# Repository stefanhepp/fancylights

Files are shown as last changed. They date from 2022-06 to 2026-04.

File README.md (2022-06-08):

FancyLights
===========

This is the sourcecode and plans for my home LED light and projector control system.

Content
=======

This project consists of the following controller boards:
- `keypad`: Sources for a keypad controller that communicates via RS232 with the main controller board and via I2C with a Raspberry PI.
- `fancycontrol`: Sources for the main light controller, which controls the lights and screen, and communicates via I2C with the projector control board.
- `projector`: Sources for the projector control board, which controls a servo for the projector mount locking mechanism and communicates via RS232 with the projector.

This repository contains the following folders:
- `kicad`: KiCAD schematics for all boards.
- `src`: Sources for all AtMega microcontrollers.

License
=======

This program is free software: you can redistribute it and/or modify
it under the terms of the GNU General Public License as published by
the Free Software Foundation, either version 3 of the License, or
(at your option) any later version.

This program is distributed in the hope that it will be useful,
but WITHOUT ANY WARRANTY; without even the implied warranty of
MERCHANTABILITY or FITNESS FOR A PARTICULAR PURPOSE.  See the
GNU General Public License for more details.

You should have received a copy of the GNU General Public License
along with this program.  If not, see <https://www.gnu.org/licenses/>.

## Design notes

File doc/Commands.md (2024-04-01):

Commands
========

Keypad
------

I2C: Slave Addr

o) I2C Receive
- 3D On
- 3D Format
- Set RBG Color: 
- Light On
- Light Off
- Set Brightness
- Projector Up
- Projector Down

UART: 

o) UART Send
- 

Controller
----------

UART Projector:

o) UART Projector Send:
- 

o) UART Projector Receive:
- 

Acer 650
--------

UART: 9600baud

o) UART Send
- Power On:  2a 20 30 20 49 52 20 30 30 31 0d
- Power Off: 2a 20 30 20 49 52 20 30 30 32 0d
- Mute:      2a 20 30 20 49 52 20 30 30 36 0d
- Volume Up: 2a 20 30 20 49 52 20 30 32 33 0d
- Volume Dn: 2a 20 30 20 49 52 20 30 32 34 0d
- Eco Mode:  2a 20 30 20 49 52 20 30 35 31 0d
- 3D On:     2a 20 30 20 49 52 20 30 35 36 0d
- 3D Off:    2a 20 30 20 49 52 20 30 35 37 0d
- 2D to 3D On:  2a 20 30 20 49 52 20 30 35 38 0d
- 2D to 3D Off: 2a 20 30 20 49 52 20 30 35 39 0d
- 3D SbS Half:  2a 20 30 20 49 52 20 30 36 32 0d
- 3D SbS Full:  2a 20 30 20 49 52 20 30 36 33 0d
- 3D Top/Btm:   2a 20 30 20 49 52 20 30 36 34 0d
- 3D L/R invert: 2a 20 30 20 49 52 20 30 36 35 0d 

- Query Lamp hours:  2a 20 30 20 4c 61 6d 70 0d
- Query Lamp On/Off: 2a 20 30 20 4c 61 6d 70 20 3f 0d

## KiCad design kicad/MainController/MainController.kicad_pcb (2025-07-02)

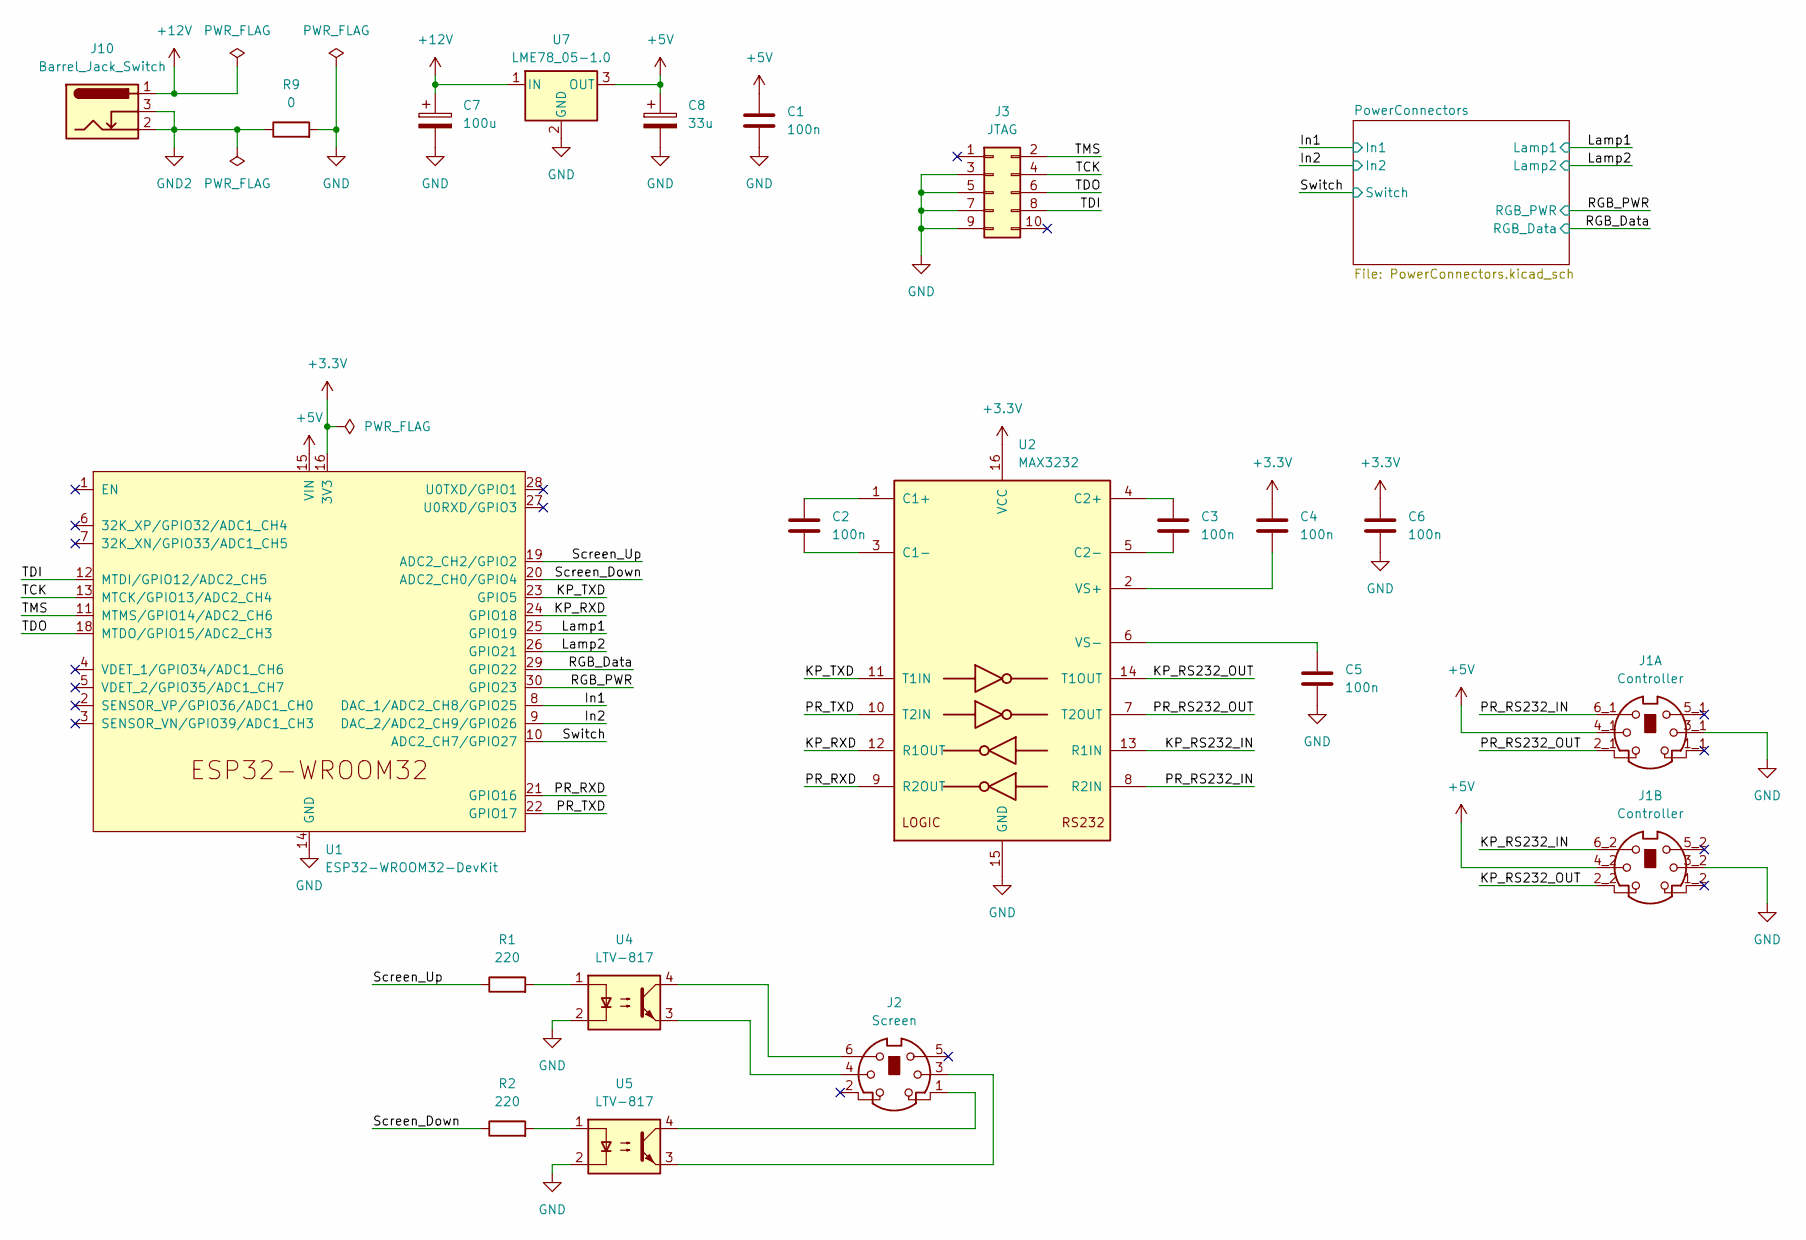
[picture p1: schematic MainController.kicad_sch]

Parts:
C1, C2, C3, C4, C5, C6: 100n; C_Disc_D3.4mm_W2.1mm_P2.50mm
C7: 100u; CP_Radial_D7.5mm_P2.50mm
C8: 33u; CP_Radial_D5.0mm_P2.50mm
J1: Controller; SWITCHCRAFT_DMD6FRA111
J2: Screen; MiniDIN TE_5749180-1
J3: JTAG; IDC-Header_2x05_P2.54mm_Vertical
J10: Barrel_Jack_Switch; BarrelJack_Horizontal
R1, R2: 220; R_Axial_DIN0207_L6.3mm_D2.5mm_P10.16mm_Horizontal
R9: 0; R_Axial_DIN0207_L6.3mm_D2.5mm_P10.16mm_Horizontal
U1: ESP32-WROOM32-DevKit; ESP32-WROOM32-DevKit_NoMountingHoles
U2: MAX3232; SOIC-16_3.9x9.9mm_P1.27mm
U4, U5: LTV-817; DIP-4_W7.62mm
U7: LME78_05-1.0; Converter_DCDC_GAPTEC_LME78_05-1.0

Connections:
+3.3V: C4.2, C6.1, U1.16 (3V3), U2.16 (VCC)
+5V: C1.1, C8.1, J1.4_1, J1.4_2, U1.15 (VIN), U7.3 (OUT); also elsewhere on the board
+12V: C7.1, J10.1, U7.1 (IN); also elsewhere on the board
/In1: U1.8 (DAC_1/ADC2_CH8/GPIO25); also elsewhere on the board
/In2: U1.9 (DAC_2/ADC2_CH9/GPIO26); also elsewhere on the board
/KP_RS232_IN: J1.6_2, U2.13 (R1IN)
/KP_RS232_OUT: J1.2_2, U2.14 (T1OUT)
/KP_RXD: U1.24 (GPIO18), U2.12 (R1OUT)
/KP_TXD: U1.23 (GPIO5), U2.11 (T1IN)
/Lamp1: U1.25 (GPIO19); also elsewhere on the board
/Lamp2: U1.26 (GPIO21); also elsewhere on the board
/PR_RS232_IN: J1.6_1, U2.8 (R2IN)
/PR_RS232_OUT: J1.2_1, U2.7 (T2OUT)
/PR_RXD: U1.21 (GPIO16), U2.9 (R2OUT)
/PR_TXD: U1.22 (GPIO17), U2.10 (T2IN)
/RGB_Data: U1.29 (GPIO22); also elsewhere on the board
/RGB_PWR: U1.30 (GPIO23); also elsewhere on the board
/Screen_Down: R2.1, U1.20 (ADC2_CH0/GPIO4)
/Screen_Up: R1.1, U1.19 (ADC2_CH2/GPIO2)
/Switch: U1.10 (ADC2_CH7/GPIO27); also elsewhere on the board
/TCK: J3.4, U1.13 (MTCK/GPIO13/ADC2_CH4)
/TDI: J3.8, U1.12 (MTDI/GPIO12/ADC2_CH5)
/TDO: J3.6, U1.18 (MTDO/GPIO15/ADC2_CH3)
/TMS: J3.2, U1.11 (MTMS/GPIO14/ADC2_CH6)
GND: C1.2, C5.2, C6.2, C7.2, C8.2, J1.3_1, J1.3_2, J3.3, J3.5, J3.7, J3.9, R9.2, U1.14 (GND), U1.17 (GND), U2.15 (GND), U4.2, U5.2, U7.2 (GND); also elsewhere on the board
GND2: J10.2, J10.3, R9.1; also elsewhere on the board
unnamed: J2.1, U5.4
unnamed: J2.3, U5.3
unnamed: J2.4, U4.3
unnamed: J2.6, U4.4
unnamed: R1.2, U4.1
unnamed: R2.2, U5.1
unnamed: C2.1, U2.1 (C1+)
unnamed: C2.2, U2.3 (C1-)
unnamed: C3.1, U2.4 (C2+)
unnamed: C3.2, U2.5 (C2-)
unnamed: C4.1, U2.2 (VS+)
unnamed: C5.1, U2.6 (VS-)

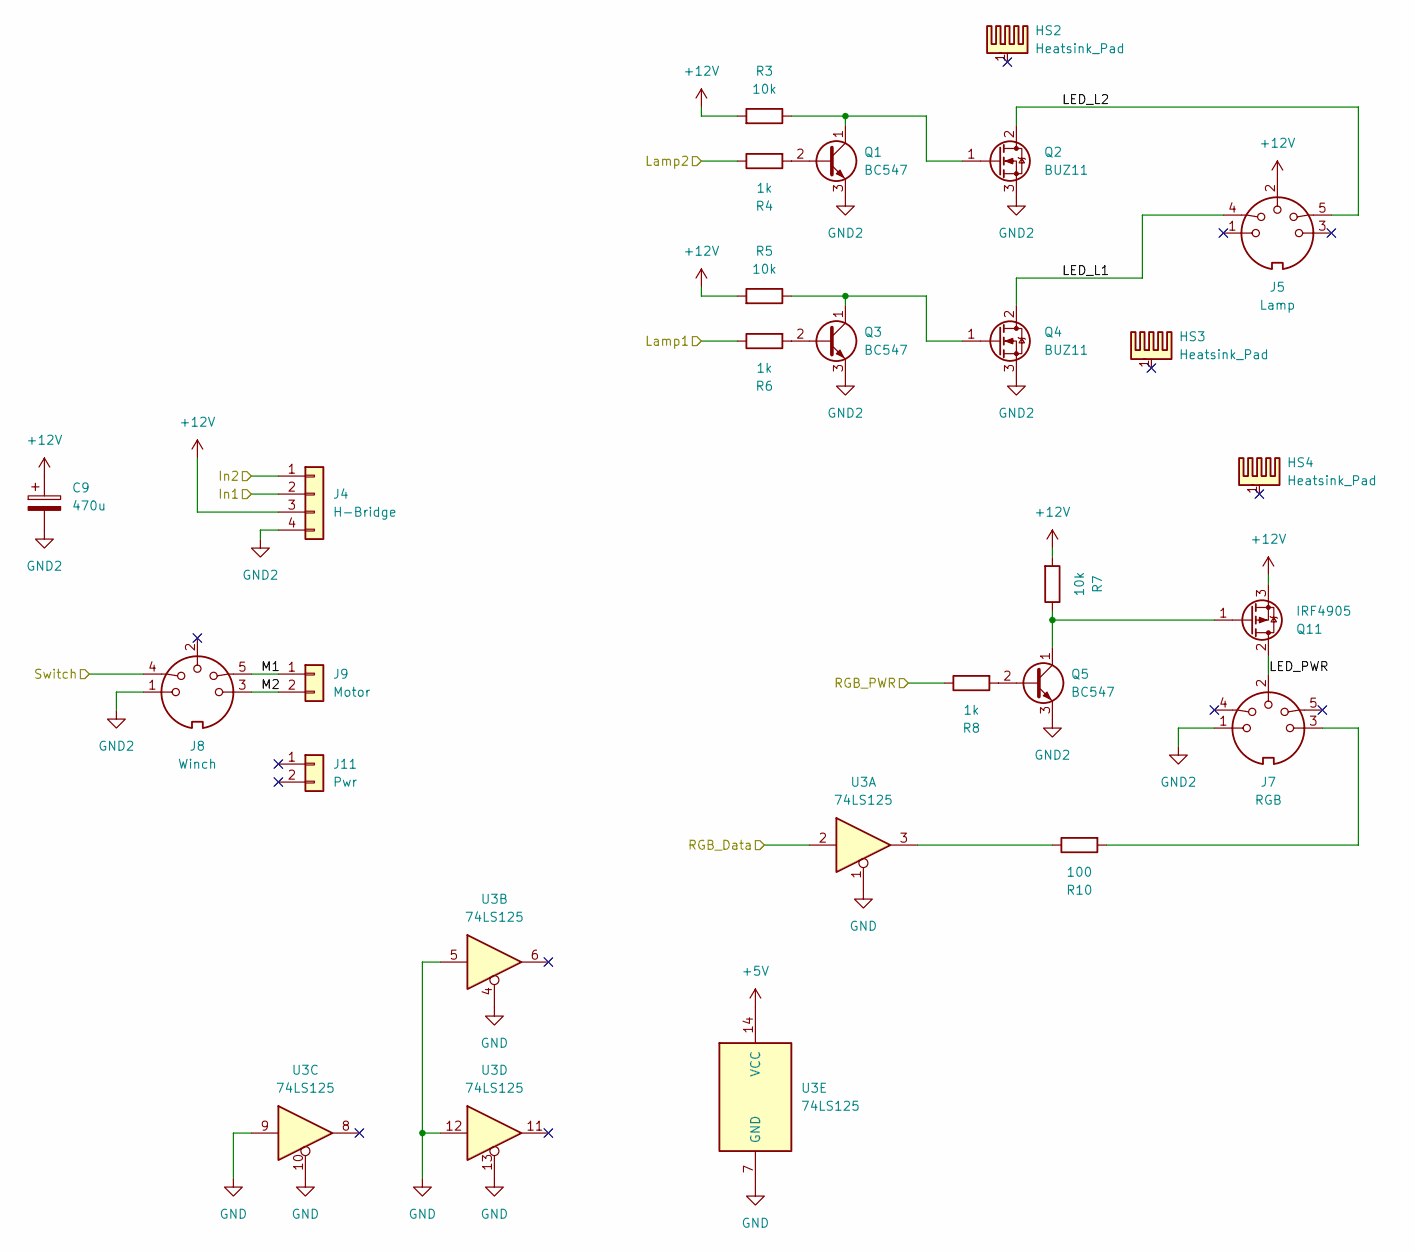
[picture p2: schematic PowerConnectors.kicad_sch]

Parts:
C9: 470u; CP_Radial_D10.0mm_P5.00mm
HS2, HS3, HS4: Heatsink_Pad; Heatsink_Aavid_TO-220_H12.7mm
J4: H-Bridge; PinHeader_1x04_P2.54mm_Vertical
J5: Lamp; DIN-5 MAB5P
J7: RGB; DIN-5 MAB5P
J8: Winch; DIN-5 MAB5P
J9: Motor; PinHeader_1x02_P2.54mm_Vertical
J11: Pwr; PinHeader_1x02_P2.54mm_Vertical
Q1, Q3, Q5: BC547; TO-92_Milling
Q2, Q4: BUZ11; TO-220-3_Vertical
Q11: IRF4905; TO-220-3_Vertical
R3, R5: 10k; R_Axial_DIN0207_L6.3mm_D2.5mm_P2.54mm_Vertical
R4, R6, R8: 1k; R_Axial_DIN0207_L6.3mm_D2.5mm_P10.16mm_Horizontal
R7: 10k; R_Axial_DIN0207_L6.3mm_D2.5mm_P10.16mm_Horizontal
R10: 100; R_Axial_DIN0207_L6.3mm_D2.5mm_P10.16mm_Horizontal
U3: 74LS125; DIP-14_W7.62mm

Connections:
+5V: U3.14 (VCC); also elsewhere on the board
+12V: C9.1, J4.3, J5.2, Q11.3 (S), R3.2, R5.2, R7.2; also elsewhere on the board
/In1: J4.2; also elsewhere on the board
/In2: J4.1; also elsewhere on the board
/Lamp1: R6.1; also elsewhere on the board
/Lamp2: R4.1; also elsewhere on the board
/PowerConnectors/LED_L1: J5.4, Q4.2 (D)
/PowerConnectors/LED_L2: J5.5, Q2.2 (D)
/PowerConnectors/LED_PWR: J7.2, Q11.2 (D)
/PowerConnectors/M1: J8.5, J9.1
/PowerConnectors/M2: J8.3, J9.2
/RGB_Data: U3.2; also elsewhere on the board
/RGB_PWR: R8.1; also elsewhere on the board
/Switch: J8.4; also elsewhere on the board
GND: U3.1, U3.4, U3.5, U3.7 (GND), U3.9, U3.10, U3.12, U3.13; also elsewhere on the board
GND2: C9.2, J4.4, J7.1, J8.1, Q1.3 (E), Q2.3 (S), Q3.3 (E), Q4.3 (S), Q5.3 (E); also elsewhere on the board
unnamed: J7.3, R10.2
unnamed: Q1.2 (B), R4.2
unnamed: Q1.1 (C), Q2.1 (G), R3.1
unnamed: Q3.2 (B), R6.2
unnamed: Q3.1 (C), Q4.1 (G), R5.1
unnamed: Q5.2 (B), R8.2
unnamed: Q5.1 (C), Q11.1 (G), R7.1
unnamed: R10.1, U3.3

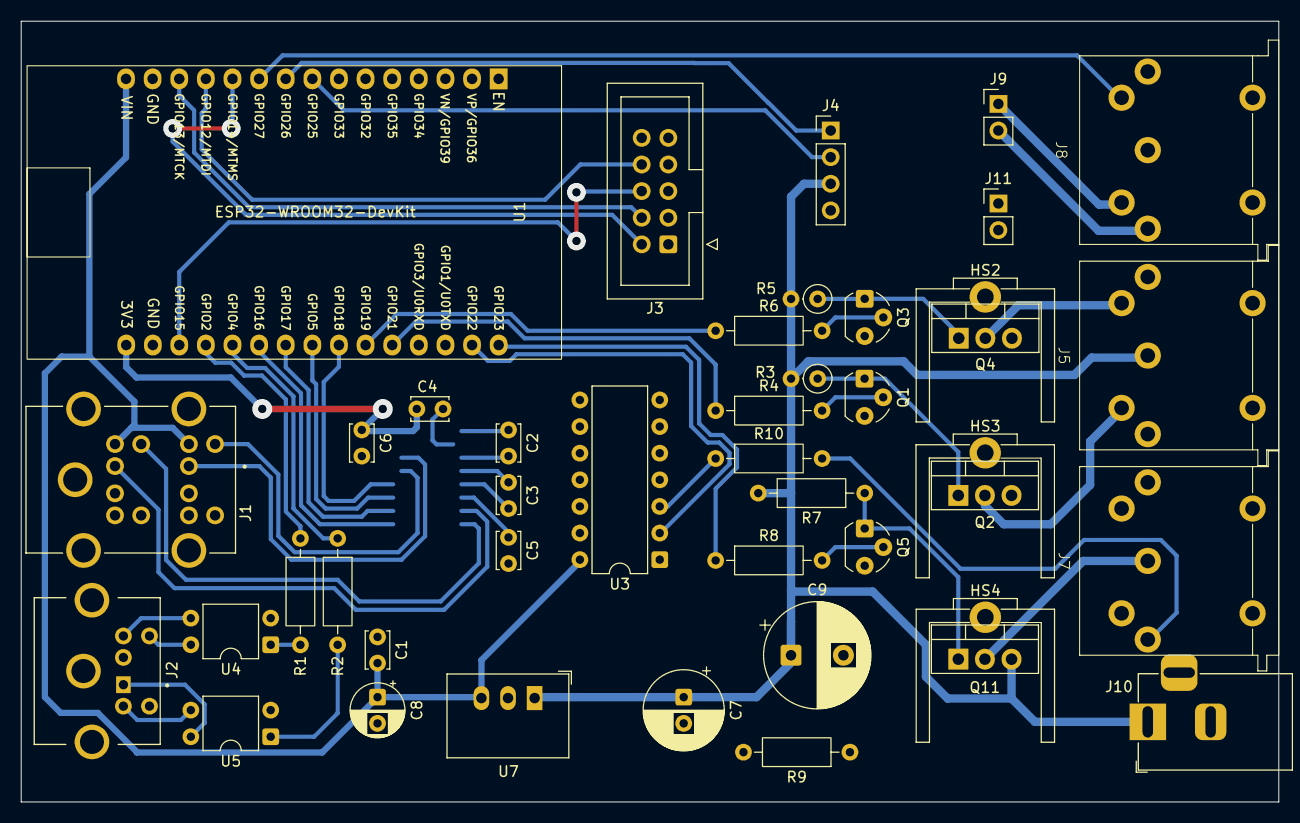
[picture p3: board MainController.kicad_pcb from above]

Board: 2 copper layers, 120.0 x 74.5 mm, 44 parts (1 on the bottom side), 51 nets.

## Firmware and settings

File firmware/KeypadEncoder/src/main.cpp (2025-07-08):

/*
 * @project     FancyController
 * @author      Stefan Hepp, stefan@stefant.org
 *
 * Keypad main loop implementation.
 *
 * Copyright 2024 Stefan Hepp
 * License: GPL v3
 * See 'COPYRIGHT.txt' for copyright and licensing information.
 */
#include <Arduino.h>
#include <MegaWire.h>

#include <commands.h>

#include "config.h"
#include "Keypad.h"
#include "LightState.h"

// Create device driver instances
MegaWire Wire;

Keypad keypad;
LightState LState;

bool LightSwitch = true;

bool StatusReceived = false;

// Toggle projector power after receiving the status from the controller back
bool ToggleProjectorPowerOnStatus = false;

static const uint8_t IRQ_COMMAND = 0;
static const uint8_t IRQ_STATUS = 1;

static uint16_t IRQFlags = 0x00;

static uint8_t I2CCommand = 0x00;

static const int I2C_BUFFER_SIZE = 16;
static uint8_t I2CBuffer[I2C_BUFFER_SIZE];
static uint8_t I2CBufferLength = 0;

static const int UART_BUFFER_SIZE = 16;
static uint8_t UARTBuffer[UART_BUFFER_SIZE];
static uint8_t UARTBufferLength = 0;

static void sendIRQ(uint8_t flag)
{
    IRQFlags |= (1<<flag);
    digitalWrite(PIN_INTERRUPT, HIGH);
}

static void clearIRQ(uint8_t flag)
{
    IRQFlags &= ~(1<<flag);
    if (IRQFlags == 0x00) {
        digitalWrite(PIN_INTERRUPT, LOW);
    }
}

void sendCommand(uint8_t command, uint8_t value, bool sendI2C = true) 
{
    switch (command) {
        case CommandOpcode::CMD_LIGHT_MODE:
            LState.setLightMode(value);
            break;
        case CommandOpcode::CMD_LIGHT_INTENSITY:
            LState.setIntensity(value);
            break;       
        case CommandOpcode::CMD_RGB_MODE:
            LState.setRGBMode(value);
            break;
        case CommandOpcode::CMD_PROJECTOR_MODE:
            LState.setProjectorMode(value);
            break;
    }

    Serial.write(CMD_HEADER | command);
    Serial.write(value);

    if (sendI2C) {
        noInterrupts();
        if (I2CBufferLength < I2C_BUFFER_SIZE - 1) {
            I2CBuffer[I2CBufferLength++] = CMD_HEADER | command;
            I2CBuffer[I2CBufferLength++] = value;
        }
        interrupts();
        sendIRQ(IRQ_COMMAND);
    }
}

void requestStatus() {
    clearIRQ(IRQ_STATUS);
    sendCommand(CommandOpcode::CMD_REQUEST_STATUS, 0, false);
}

void sendHSVColor(bool sendI2C = true)
{
    Serial.write(CMD_HEADER | CMD_HSV_COLOR);
    Serial.write(LState.hsv(0));
    Serial.write(LState.hsv(1));
    Serial.write(LState.hsv(2));

    requestStatus();
}

void processKeypadCommand(uint8_t data)
{
    if (UARTBufferLength == 0 && (data & CMD_HEADER) != CMD_HEADER) {
        // Wait for command byte, drop other data
        return;
    }

    if (UARTBufferLength < UART_BUFFER_SIZE) {
        UARTBuffer[UARTBufferLength++] = data;
    }

    switch (UARTBuffer[0] & ~CMD_HEADER) {
        case CMD_READ_STATUS:
            if (UARTBufferLength >= 9) {
                // command completely received
                LState.setLightMode(UARTBuffer[1]);
                LState.setIntensity(UARTBuffer[2]);
                LState.setDimmedIntensity(UARTBuffer[3]);
                LState.setProjectorMode(UARTBuffer[4]);
                LState.setRGBMode(UARTBuffer[5]);
                LState.setHSV(UARTBuffer[6], UARTBuffer[7], UARTBuffer[8]);

                UARTBufferLength = 0;
                StatusReceived = true;

                // We got a new status, inform RPi to fetch the new status
                sendIRQ(IRQ_STATUS);

                if (ToggleProjectorPowerOnStatus) {
                    // If this status was requested by a Projector power toggle button, perform the action now.
                    LState.toggleProjector();
                    sendCommand(CMD_PROJECTOR_MODE, LState.projectorMode());
                    
                    ToggleProjectorPowerOnStatus = false;
                }
            }
            break;
        default:
            // unknown command, drop
            UARTBufferLength = 0;
            break;
    }
}

void onButtonPress(uint8_t btn, bool longPress)
{
    switch (btn) {
        case 0: // 3D mode
            sendCommand(CMD_PROJECTOR_MODE, PROJECTOR_3D);
            sendCommand(CMD_RGB_MODE, RGB_DIMMED);
            break;
        case 1: // VR mode
            sendCommand(CMD_PROJECTOR_MODE, PROJECTOR_VR);
            sendCommand(CMD_RGB_MODE, RGB_ON);
            break;
        case 2: // Color cycle forward
            if (longPress) {
                sendCommand(CMD_RGB_MODE, RGB_CYCLE);
            } else if (LState.rgbMode() != RGB_ON) {
                sendCommand(CMD_RGB_MODE, RGB_ON);
            } else {
                LState.changeHSVHue(16);
                sendHSVColor();
            }
            break;
        case 3: // Color cycle back
            if (longPress) {
                sendCommand(CMD_RGB_MODE, RGB_CYCLE);
            } else if (LState.rgbMode() != RGB_ON) {
                sendCommand(CMD_RGB_MODE, RGB_ON);
            } else {
                LState.changeHSVHue(-16);
                sendHSVColor();
            }
            break;
        case 4: // Fire mode
            sendCommand(CMD_RGB_MODE, RGB_FIRE);
            break;
        case 5: // Movie mode
            sendCommand(CMD_PROJECTOR_MODE, PROJECTOR_NORMAL);
            sendCommand(CMD_RGB_MODE, longPress ? RGB_ON : RGB_DIMMED);
            break;
        case 6: // RGB saturation down
            LState.changeHSVSaturation(longPress ? -255 : -32);
            sendHSVColor();
            break;
        case 7: // RGB saturation up
            LState.changeHSVSaturation(longPress ? 255 : 32);
            sendHSVColor();
            break;
        case 8: // Screen down
            if (longPress) {
                sendCommand(CMD_SCREEN, LIFT_STOP);
            } else {
                sendCommand(CMD_SCREEN, LIFT_DOWN);
            }        
            break;
        case 9: // Screen up
            if (longPress) {
                sendCommand(CMD_SCREEN, LIFT_STOP);
            } else {
                sendCommand(CMD_SCREEN, LIFT_UP);
            }        
            break;
        case 10: // Intensity down
            LState.changeIntensity(longPress ? -255 : -32);
            sendCommand(CMD_LIGHT_INTENSITY, LState.lightIntensity());
            sendHSVColor();
            break;
        case 11: // Intensity up
            LState.changeIntensity(longPress ? 255 : 32);
            sendCommand(CMD_LIGHT_INTENSITY, LState.lightIntensity());
            sendHSVColor();
            break;
        case 12: // Projector down
            if (longPress) {
                sendCommand(CMD_PROJECTOR_LIFT, LIFT_STOP);    
            } else {
                sendCommand(CMD_PROJECTOR_LIFT, LIFT_DOWN);
            }        
            break;
        case 13: // Projector up
            if (longPress) {
                sendCommand(CMD_PROJECTOR_LIFT, LIFT_STOP);    
            } else {
                sendCommand(CMD_PROJECTOR_LIFT, LIFT_UP);
            }
            break;
        case 14: // Projector on/off
            // Read the status of the projector first, Delay toggling till we receive the message
            ToggleProjectorPowerOnStatus = true;
            sendCommand(CMD_REQUEST_STATUS, 0);
            break;
        case 15: // Light on/off
            LState.toggleLight();
            sendCommand(CMD_LIGHT_MODE, LState.lightMode());
            break;
    }
}

void i2cReceive(uint8_t length) {
    uint8_t I2CCommand = Wire.read();
    uint8_t value;

    switch (I2CCommand) {
        case CommandOpcode::CMD_LIGHT_MODE:
        case CommandOpcode::CMD_LIGHT_INTENSITY:
        case CommandOpcode::CMD_DIMMED_INTENSITY:
        case CommandOpcode::CMD_RGB_MODE:
        case CommandOpcode::CMD_SCREEN:
        case CommandOpcode::CMD_PROJECTOR_MODE:
        case CommandOpcode::CMD_PROJECTOR_LIFT:
            value = Wire.read();

            // Forward command to controller
            sendCommand(I2CCommand, value, false);
            break;
        case CommandOpcode::CMD_HSV_COLOR:
            if (Wire.available() > 2) {
                LState.setHSV(Wire.read(), 
                              Wire.read(), 
                              Wire.read());
                sendHSVColor(false);
            }
            break;
        case CommandOpcode::CMD_REQUEST_STATUS:
            requestStatus();
            break;
        case CommandOpcode::CMD_READ_COMMANDS:
        case CommandOpcode::CMD_READ_STATUS:
            // expect i2c read request after this write
            break;
    }
}

void i2cRequest()
{
    switch (I2CCommand) {
        case CommandOpcode::CMD_READ_COMMANDS:
            Wire.write(I2CBufferLength | (IRQFlags & (1<<IRQ_STATUS) ? 0x80 : 0) );

            for (uint8_t i = 0; i < I2CBufferLength; i++) {
                Wire.write(I2CBuffer[i]);
            }

            I2CBufferLength = 0;

            clearIRQ(IRQ_COMMAND);
            break;
        case CommandOpcode::CMD_READ_STATUS:
            Wire.write(LState.lightMode());
            Wire.write(LState.lightIntensity());
            Wire.write(LState.dimmedIntensity());
            Wire.write(LState.projectorMode());
            Wire.write(LState.rgbMode());
            Wire.write(LState.hsv(0));
            Wire.write(LState.hsv(1));
            Wire.write(LState.hsv(2));

            clearIRQ(IRQ_STATUS);
            break;
    }
}

void setup() {
    // Enable pullups for unconnected pins
    pinMode(PIN_PB1, INPUT_PULLUP);
    pinMode(PIN_PB2, INPUT_PULLUP);
    pinMode(PIN_PB3, INPUT_PULLUP);
    pinMode(PIN_PB4, INPUT_PULLUP);
    pinMode(PIN_PB5, INPUT_PULLUP);
    pinMode(PIN_PB6, INPUT_PULLUP);
    pinMode(PIN_PB7, INPUT_PULLUP);
    pinMode(PIN_PC6, INPUT_PULLUP);
    pinMode(PIN_PD3, INPUT_PULLUP);

    pinMode(PIN_SWITCH, INPUT_PULLUP);

    // Set output pin modes
    // Set pin value first before turing on output mode, to prevent spurious signals
    digitalWrite(PIN_INTERRUPT, LOW);
    pinMode(PIN_INTERRUPT, OUTPUT);

    Wire.onReceive(i2cReceive);
    Wire.onRequest(i2cRequest);
    keypad.setPressEvent(onButtonPress);

    Serial.begin(UART_SPEED_CONTROLLER);

    Wire.begin(KEYPAD_I2C_ADDR);
    keypad.begin();

    StatusReceived = true;
    delay(500);
    sendCommand(CMD_REQUEST_STATUS, 0);
}

void loop() {
    if (StatusReceived) {
        keypad.poll();

        uint8_t newSwitchState = digitalRead(PIN_SWITCH);
        if (newSwitchState != LightSwitch) {
            LState.toggleLight();

            sendCommand(CMD_LIGHT_MODE, LState.lightMode());

            LightSwitch = newSwitchState;
        }
    }

    while (Serial.available()) {
        int data = Serial.read();

        processKeypadCommand(data);
    }
}

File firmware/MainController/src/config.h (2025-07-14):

/*
 * @project     FancyLights
 * @author      Stefan Hepp, stefan@stefant.org
 *
 * common custom IO and config settings.
 *
 * Copyright (c) 2024 Stefan Hepp
 * License: GPL v3
 * See 'COPYRIGHT.txt' for copyright and licensing information.
 */
#pragma once

#include <Arduino.h>

/* ==================================================== */
/* Common controller settings                           */
/* ==================================================== */

static const uint8_t PIN_RGB_DATA     = 22;
static const uint8_t PIN_RGB_PWR      = 23;
static const uint8_t PIN_LAMP1        = 19;
static const uint8_t PIN_LAMP2        = 21;
static const uint8_t PIN_SCREEN_UP    = 4;
static const uint8_t PIN_SCREEN_DOWN  = 2;
static const uint8_t PIN_WINCH_SWITCH = 27;
static const uint8_t PIN_MOTOR_IN1    = 25;
static const uint8_t PIN_MOTOR_IN2    = 26;

static const uint8_t UART_KEYPAD      = 1;
static const uint8_t UART_PROJECTOR   = 2;

static const uint8_t PIN_KP_TXD       = 5;
static const uint8_t PIN_KP_RXD       = 18;
static const uint8_t PIN_PR_TXD       = 17;
static const uint8_t PIN_PR_RXD       = 16;

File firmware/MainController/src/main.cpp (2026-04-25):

/*
 * @project     FancyLights
 * @author      Stefan Hepp, stefan@stefant.org
 *
 * Controller main loop implementation.
 *
 * Copyright 2024 Stefan Hepp
 * License: GPL v3
 * See 'COPYRIGHT.txt' for copyright and licensing information.
 */

#include <Arduino.h>

#include <WiFi.h>
#include <PubSubClient.h>
#include <FastLED.h>

#include <commands.h>

#include "config.h"
#include "CommandLine.h"
#include "LED.h"
#include "Settings.h"
#include "ProjectorController.h"
#include "KeypadDriver.h"
#include "MqttClient.h"

Settings settings;
CommandLine cmdline;
MqttClient mqttClient(settings);
LEDDriver LEDs(settings, mqttClient);
ProjectorController Projector(settings, mqttClient);
KeypadDriver Keypad(settings, LEDs, Projector);


class StatusParser: public CommandParser
{
    public:
        StatusParser() {}

        virtual CmdExecStatus completeCommand(bool expectCommand) {
            IPAddress mqttAddr;
            WiFi.hostByName(settings.getMQTTServer().c_str(), mqttAddr);

            Serial.printf("Enable Lamp: %s, LED Strip: %s\n", strBool(LEDs.isLampEnabled()), strBool(LEDs.isLEDStripEnabled()));
            Serial.printf("Light Intensity: %hhu\n", LEDs.intensity());
            Serial.printf("Dimmed Intensity: %hhu\n", LEDs.dimmedIntensity());
            Serial.printf("RGB Strip Mode: %s\n", strRGBMode(LEDs.rgbMode()));
            Serial.printf("Projector Mode: %s\n", strProjectorCommand(Projector.mode()));
            Serial.printf("HSV: %hhu %hhu %hhu\n", LEDs.getHSV().hue, LEDs.getHSV().sat, LEDs.getHSV().val);
            Serial.printf("WiFi SSID: %s PW: %s\n", settings.getWiFiSSID(), settings.getWiFiPassword());
            Serial.printf("WiFi Hostname %s IP %s DNS %s\n", WiFi.getHostname(), WiFi.localIP().toString(), WiFi.dnsIP().toString());
            Serial.printf("WiFi Status (%d) %s\n", WiFi.status(), WiFi.status() == WL_CONNECTED ? "connected" : "not connected");
            Serial.printf("MQTT Server %s:%d IP: %s\n", settings.getMQTTServer(), settings.getMQTTPort(), mqttAddr.toString());
            Serial.printf("MQTT Client %s Topic %s\n", settings.getMQTTClientID(), settings.getMQTTTopic());
            Serial.printf("MQTT User %s Pass: %s\n", settings.getMQTTUsername(), settings.getMQTTPassword());
            Serial.printf("MQTT Status %s\n", mqttClient.connected() ? "connected" : "not connected");

            Projector.requestStatus();

            return CmdExecStatus::CESOK;
        }
};

class WiFiParser: public CommandParser {
    private:
        enum WiFiCommand {
            WIC_NONE,
            WIC_AP,
            WIC_HOSTNAME,
            WIC_CONNECT
        };
        WiFiCommand mCmd;

        String mSSID;
        String mPassword;
        String mHostname;

    public:
        WiFiParser() {}

        virtual void printArguments() {
            Serial.print("ap <ssid> <password>|hostname <hostname>|reconnect");
        }

        virtual CmdParseStatus startCommand(const char* cmd) {
            mCmd = WIC_NONE;
            return CPSNextArgument;
        }

        virtual CmdParseStatus parseNextArgument(int argNo, const char* arg) {
            if (argNo == 0) {
                if (strcmp(arg, "ap") == 0) {
                    mCmd = WIC_AP;
                    return CPSNextArgument;
                }
                if (strcmp(arg, "hostname") == 0) {
                    mCmd = WIC_HOSTNAME;
                    return CPSNextArgument;
                }
                if (strcmp(arg, "reconnect") == 0) {
                    mCmd = WIC_CONNECT;
                    return CPSComplete;
                }
            }
            if (mCmd == WIC_AP && argNo == 1) {
                mSSID = arg;
                return CPSNextArgument;
            }
            if (mCmd == WIC_AP && argNo == 2) {
                mPassword = arg;
                return CPSComplete;
            }
            if (mCmd == WIC_HOSTNAME && argNo == 1) {
                mHostname = arg;
                return CPSComplete;
            }
            return CPSInvalidArgument;
        }

        virtual CmdExecStatus completeCommand(bool expectCommand) {
            if (mCmd == WIC_AP) {
                settings.setWiFiAccess(mSSID.c_str(), mPassword.c_str());
                WiFi.disconnect();
                WiFi.begin(mSSID.c_str(), mPassword.c_str());
                WiFi.reconnect();
                return CmdExecStatus::CESOK;
            }
            if (mCmd == WIC_HOSTNAME) {
                settings.setHostname(mHostname.c_str());
                WiFi.setHostname(mHostname.c_str());
                return CmdExecStatus::CESOK;
            }
            if (mCmd == WIC_CONNECT) {
                WiFi.disconnect();
                WiFi.reconnect();
                Serial.printf("[WiFi] Reconnect: %s status %d IP %s\n",
                              WiFi.isConnected() ? "connected" : "not connected",
                              WiFi.status(),
                              WiFi.localIP().toString().c_str());
                return CmdExecStatus::CESOK;
            }
            return CmdExecStatus::CESInvalidArgument;
        }
};
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

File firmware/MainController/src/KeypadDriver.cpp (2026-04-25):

/*
 * @project     FancyLights
 * @author      Stefan Hepp, stefan@stefant.org
 *
 * Keypad interface driver implemention.
 *
 * Copyright 2024 Stefan Hepp
 * License: GPL v3
 * See 'COPYRIGHT.txt' for copyright and licensing information.
 */

#include "KeypadDriver.h"

#include <commands.h>

#include "config.h"

HardwareSerial keypadSerial(UART_KEYPAD);

KeypadDriver::KeypadDriver(Settings &settings, LEDDriver &leds, ProjectorController &projector)
: mSettings(settings), mLEDs(leds), mProjector(projector)
{
}

void KeypadDriver::startStatusTimeout() {
    CntStatusTimeout = 80;
}

void KeypadDriver::sendStatus() {
    CntStatusTimeout = 1;
}

bool KeypadDriver::checkStatusTimeout() {
    if (CntStatusTimeout > 0) {
        CntStatusTimeout--;
        if (CntStatusTimeout == 0) {
            // Timeout reached, send status
            return true;
        }
    }
    // no timer running or not yet reached
    return false;
}

void KeypadDriver::begin()
{
    keypadSerial.begin(UART_SPEED_CONTROLLER, SERIAL_8N1, PIN_KP_RXD, PIN_KP_TXD);
}

/**
 * Send the current settings to the keypad controller.
 */
void KeypadDriver::sendKeypadStatus()
{
    keypadSerial.write(CMD_HEADER | CMD_READ_STATUS);
    keypadSerial.write((mLEDs.isLEDStripEnabled() << 1) | (mLEDs.isLampEnabled()));
    keypadSerial.write(mLEDs.intensity());
    keypadSerial.write(mLEDs.dimmedIntensity());
    keypadSerial.write(mProjector.mode());
    keypadSerial.write(mLEDs.rgbMode());
    keypadSerial.write(mLEDs.getHSV().hue);
    keypadSerial.write(mLEDs.getHSV().sat);
    keypadSerial.write(mLEDs.getHSV().val);
}

void KeypadDriver::processKeypadCommand(uint8_t data)
{
    if (UARTBufferLength == 0 && (data & CMD_HEADER) != CMD_HEADER) {
        // Wait for command byte, drop other data
        return;
    }

    if (UARTBufferLength < UART_BUFFER_SIZE) {
        UARTBuffer[UARTBufferLength++] = data;
    }

    switch (UARTBuffer[0] & ~CMD_HEADER) {
        case CMD_LIGHT_INTENSITY:
            if (UARTBufferLength >= 2) {
                Serial.printf("[Kbd] Set light intensity: %hhu\n", UARTBuffer[1]);
                mLEDs.setIntensity(UARTBuffer[1]);
                UARTBufferLength = 0;
            }
            break;
        case CMD_DIMMED_INTENSITY:
            if (UARTBufferLength >= 2) {
                Serial.printf("[Kbd] Set dimmed intensity: %hhu\n", UARTBuffer[1]);
                mLEDs.setDimmedIntensity(UARTBuffer[1]);
                UARTBufferLength = 0;
            }
            break;
        case CMD_HSV_COLOR:
            if (UARTBufferLength >= 4) {
                Serial.printf("[Kbd] Set HSV: %hhu %hhu %hhu\n", UARTBuffer[1], UARTBuffer[2], UARTBuffer[3]);
                mLEDs.setHSV(UARTBuffer[1], UARTBuffer[2], UARTBuffer[3]);
                UARTBufferLength = 0;
            }
            break;
        case CMD_LIGHT_MODE:
            if (UARTBufferLength >= 2) {
                Serial.printf("[Kbd] Enable lamp: %s, LED strip: %s\n", strBool(UARTBuffer[1] & 0x01), strBool(UARTBuffer[1] & 0x02));
                mLEDs.enableLamps(UARTBuffer[1] & 0x01);
                mLEDs.enableLEDStrip(UARTBuffer[1] & 0x02);
                UARTBufferLength = 0;
            }
            break;
        case CMD_RGB_MODE:
            if (UARTBufferLength >= 2) {
                Serial.printf("[Kbd] Set RGB mode: %s\n", strRGBMode((RGBMode) UARTBuffer[1]));
                mLEDs.setRGBMode((RGBMode) UARTBuffer[1]);
                UARTBufferLength = 0;
            }
            break;
        case CMD_SCREEN:
            if (UARTBufferLength >= 2) {
                Serial.printf("[Kbd] Move Screen: %s\n", strLiftCommand((LiftCommand) UARTBuffer[1]));
                mProjector.moveScreen((LiftCommand) UARTBuffer[1]);
                UARTBufferLength = 0;
            }
            break;
        case CMD_PROJECTOR_MODE:
            if (UARTBufferLength >= 2) {
                Serial.printf("[Kbd] Set projector mode: %s\n", strProjectorCommand((ProjectorCommand) UARTBuffer[1]));
                mProjector.sendMode((ProjectorCommand) UARTBuffer[1]);
                UARTBufferLength = 0;
            }
            break;
        case CMD_PROJECTOR_LIFT:
            if (UARTBufferLength >= 2) {
                Serial.printf("[Kbd] Lift projector: %s\n", strLiftCommand((LiftCommand) UARTBuffer[1]));
                mProjector.moveProjector((LiftCommand) UARTBuffer[1]);
                UARTBufferLength = 0;
            }
            break;
        case CMD_REQUEST_STATUS:
            if (UARTBufferLength >= 2) {
                mProjector.requestStatus();
                startStatusTimeout();
                UARTBufferLength = 0;
            }
            break;
        default:
            // unknown command, drop
            UARTBufferLength = 0;
            break;
    }
}

void KeypadDriver::loop()
{
    // Process keypad UART cmds
    while (keypadSerial.available()) {
        char data = keypadSerial.read();

        processKeypadCommand(data);
    }

    EVERY_N_MILLISECONDS( 10 ) {
        // Check if we need to send status to keypad
        bool timeout = checkStatusTimeout();
        bool changed = mSettings.hasChanged();
        
        if (timeout || changed) {
            sendKeypadStatus();
        }

        mSettings.clearChanged();
    }

}

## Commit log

2024-02-27 Added Boards connections draw.io file
2024-03-29 Added keypad schematics
    [KeypadController.kicad_pcb, KeypadController.kicad_sch, KeypadWires.kicad_pcb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]
2024-03-29 Fixed keypad wiring schematics
    [KeypadController.kicad_sch, KeypadWires.kicad_sch]
2024-03-31 Added schematics for projector controller, initial source project
    [FancyController.kicad_pcb, FancyController.kicad_sch, ProjectorController.kicad_pcb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]
2024-04-01 Complete schematics, using UART for communications
    [FancyController.kicad_sch, KeypadWires.kicad_sch, PowerConnectors.kicad_sch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]
2024-11-19 Added interrupt for Raspberry PI I2C
    [KeypadController.kicad_sch]
2024-11-22 Changed RS232 pin mapping
    [FancyController.kicad_sch, PowerConnectors.kicad_sch]
2024-11-25 Fixes for keypad implementation
    [Keypad.cpp, main.cpp]
2024-11-28 Bugfixes for UART protocol
    [LED.cpp, LED.h, main.cpp]
2024-11-28 Bugfixes for LED outputs
    [LED.cpp, main.cpp]
2024-11-30 Fix HSV h value scaling
    [LED.cpp]
2025-04-10 Initial schematic for ESP32 based LED controller
    [MainController.kicad_pcb, MainController.kicad_sch, PowerConnectors.kicad_sch]
2025-04-23 New main controller PCB layout using ESP32
    [MainController.kicad_pcb, MainController.kicad_sch, PowerConnectors.kicad_sch]
2025-04-24 Updated main controller implementation for ESP32
    [MainController.kicad_pcb, MainController.kicad_sch, PowerConnectors.kicad_sch]
2025-05-08 Added debug target for ESP32
2025-05-23 Updated main controller for digital RGB strip
    [MainController.kicad_pcb, MainController.kicad_sch, PowerConnectors.kicad_sch]
2025-05-26 Fixed footprints for MainController board
    [MainController.kicad_pcb, MainController.kicad_sch, PowerConnectors.kicad_sch]
2025-06-07 Added commandline interface to main controller
    [MainController.kicad_pcb, MainController.kicad_sch]
2025-06-19 Fixes for Commandline parser
    [CommandLine.cpp, CommandLine.h, LED.cpp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]
2025-06-21 Fixes for LED intensity, added LED command
    [CommandLine.cpp, LED.cpp, main.cpp]
2025-06-21 Fixed MainController LED power and data drivers
    [MainController.kicad_pcb, MainController.kicad_sch, PowerConnectors.kicad_sch]
2025-07-01 Fixes for wifi and mqtt commands
    [main.cpp]
2025-07-02 Cleanup to PCB layout
    [MainController.kicad_pcb]
2025-07-08 Fixed Mqtt client implementation
    [LED.cpp, LED.h, MqttClient.cpp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]
2025-07-11 Implemented LED effects
2025-07-12 Fix for screen up/down pulse
    [ProjectorController.cpp, main.cpp]
2025-07-14 Fixed screen up/down pin assignment
    [MqttClient.cpp, config.h]
2026-01-07 Send MQTT updates to keypad, read projector power status
2026-04-08 Fixed fade animation, added 'light' MQTT topic
    [LED.cpp, LED.h, ProjectorController.cpp]
